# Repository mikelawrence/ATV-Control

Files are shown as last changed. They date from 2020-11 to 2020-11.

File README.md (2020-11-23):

# ATV Control PCB

This board was designed to act as a relay for two LED (V1 and V2) lights up to 7.5A each and a horn (H) up to 20A. Each LED Output has a control switch input and indicator LED output. When the Ignition input is on (12V) indicates the ATV is running so the Reverse input will turn LED V2 output on when at 12V and the High Beam input will turn LED V1 output on when at 12V. Turning Ignition off (0V) will turn off all LED outptus (V1 and V2). The control switches allows manual control the LED lights even when the ATV off. When you turn a LED on with a control switch the LED light will remain on for a configurable amount of time (1-20 minutes). This delay off will prevent the battery from being discharged.

The horn is controlled by a switch just like the LED outputs but it has three indicator LEDs (Red, Green, and Blue). When the horn control switch is pressed any currently on LED outputs (V1 or V2) will be turned off to reduce overall current throught the board. The horn will not work if Ignition is not on (12V).

## Status and Testing

* Rev 1.0 has been ordered and tested.
  * You can order parts from Mouser using this [shared BOM](https://www.mouser.com/ProjectManager/ProjectDetail.aspx?AccessID=3e10d07292).
  * You can order the PCB from [OSH Park](https://oshpark.com/shared_projects/YVj5Y8EP).

## Board Preview

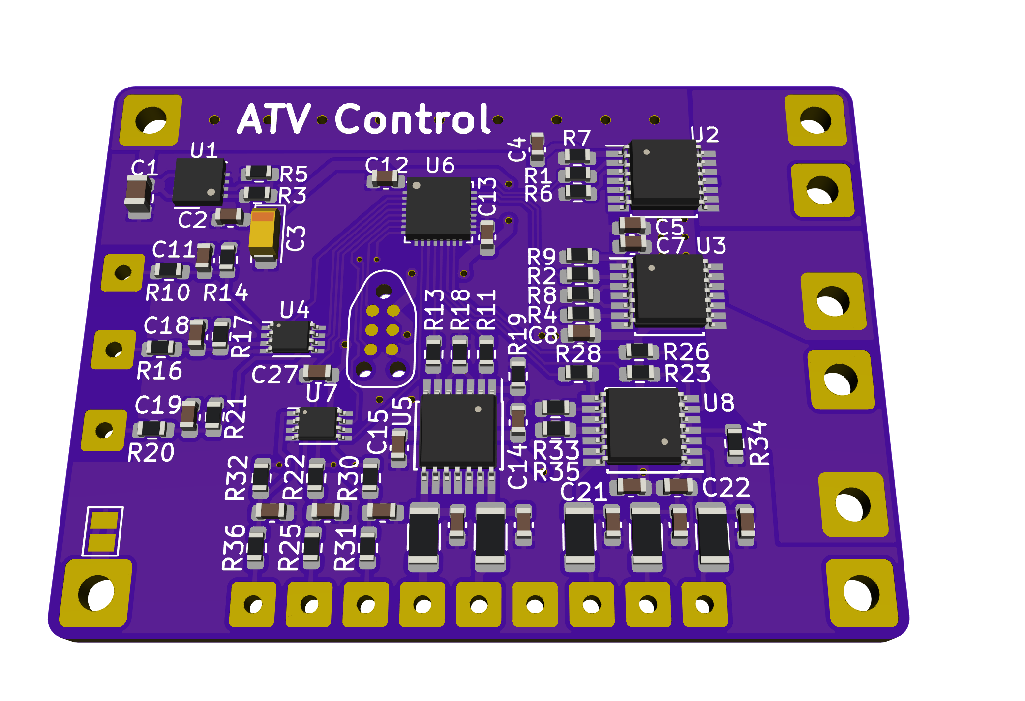
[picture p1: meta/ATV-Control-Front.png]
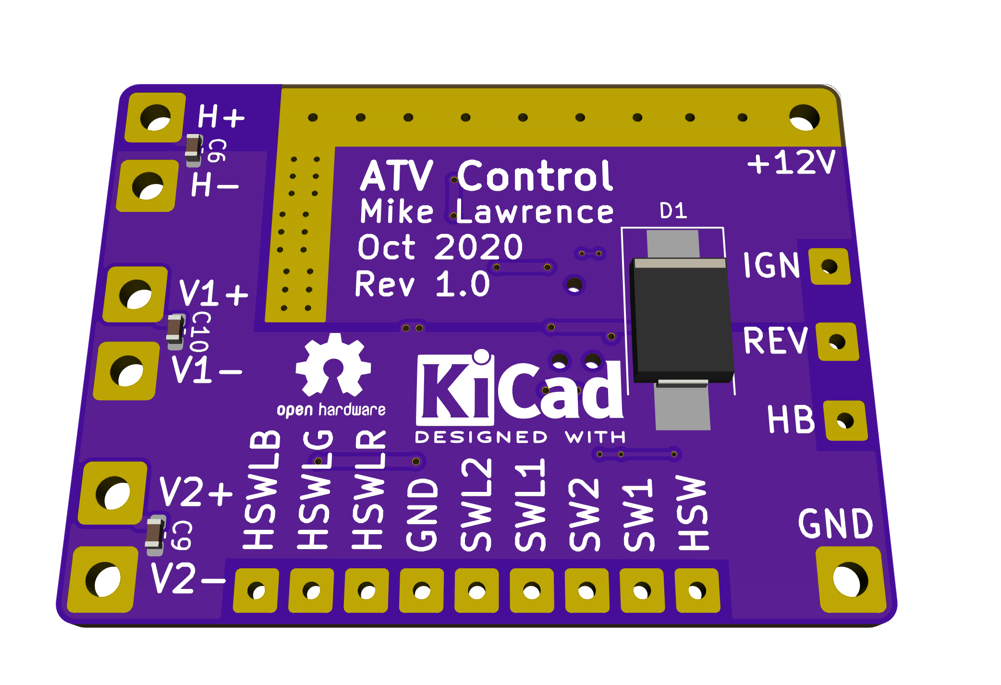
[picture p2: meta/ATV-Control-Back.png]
 

## Notes

* This board must have a 20A fuse or other safety device on the input.
* The Reverse Input is configured for my 2020 Yamaha Grizzly 700. The reverse switch is connected to ground when ATV is in reverse, otherwise it is pulled up to 12V by the Engine Control Unit. R17 is used to pulldown this input to prevent a floating input from causing problems. However this pulldown is a high enough impedance to not affect the pullup in the Engine Control Unit. You will need to adjust this input to match your specific ATV.
* The board's current usage is about than 0.25 mA when idle. This represents a small but never the less non-zero current draw on the ATV's battery even when the ignition is off. My ATV is used frequently so this is not an issue but if you plan on storing the ATV long term you should be using a trickle charger to keep the battery topped off. Or pull that 20 A fuse you added to the 12V input to this PCB.
* I used High-Side switch from Infineon for all the high current outputs. These chips are designed for automotive environments to drive resistive, capacitive, and inductive loads while providing over current, over temperature, over voltage, and reverse polarity protections. I also used these High-Side Switches for the indicator LEDs even though it is a bit overkill.
* The Horn circuit is a relatively high current at 20A. There is missing solder mask on the bottom of the PCB. It is expected that additional solder will be placed on this section to improve current handling. You should also plan on adding a 16 AWG wire between the GND input and the H- connections.
* This PCB design expects 2 oz copper for both sides.
* Assembling this PCB will require a reflow oven or hot air. [Whizoo](http://www.whizoo.com/) sells a nice kit to make your own reflow oven.
* This PCB design uses my custom libraries available here [Mike's KiCad Libraries](https://github.com/mikelawrence/KiCad-Libraries).
* PCB is designed in [KiCad](http://kicad-pcb.org) which is a great free EDA toolset.
* For Bill of Materials generation I use my version of [KiBoM](https://github.com/mikelawrence/KiBoM) forked from [SchrodingersGat](https://github.com/SchrodingersGat/KiBoM).

## Software

The microcontroller is a Atmel/Microchip XMega8E5. Software is written in C using the free [Microchip Studio for AVR](https://www.microchip.com/mplab/microchip-studio) free cross compiler and development environment. My normal AVR debugging tool is [Atmel-ICE](https://www.microchip.com/DevelopmentTools/ProductDetails/atatmel-ice). You can get it for as low as $62 in the form of a board from Digikey or Mouser. Instead of the standard programming header I use the Tag-Connect cable and it's space saving [footprint](https://www.tag-connect.com/product/tc2030-nl-fp-footprint). [This](https://www.tag-connect.com/product/tc2030-icespi-nl-no-leg-cable-for-use-with-atmel-ice) is Tag-Connect cable I use with the Atmel-ICE.

## Board Installation

I use Sugru moldable silicone to encapsulate this PCB to prevent water damage.

## End Result

The push button switches were installed in the center headlight cluster. Looking from the front the center pushbutton is the horn. The two push buttons on the right control the LED lights. The two buttons on the left are buttons for the Homelink controller ([60-HMLKV5BLK](https://www.amazon.com/gp/product/B00A79G9FY/ref=ppx_yo_dt_b_search_asin_title?ie=UTF8&psc=1)) so I can control my front gate and one garage door. This is not part of the ATV Control PCB.

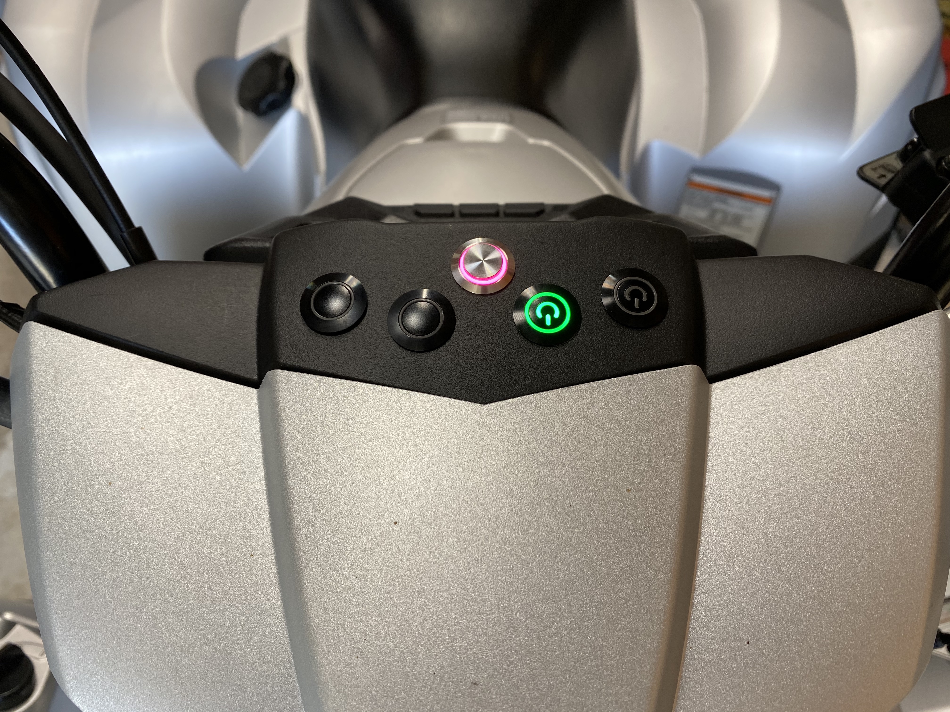
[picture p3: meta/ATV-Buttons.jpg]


For the front of the ATV I installed a Black Oak [10" Dual Row, 100W Flood LED Light Bar](https://www.blackoakled.com/collections/double-row-led/products/10-two-row-led-light-bar-combination-beam-pattern-white-osram) and two Black Oak [2" Single Row, 20W Scene LED Light Bars](https://www.blackoakled.com/products/new-2-inch-single-row-series-led-light-bar-with-scene-optics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). All three LED Light Bars draw just under 7 A which is just below the maximum current of 7.5 A for that output. I used Axia Alloy mounts for the LED Light Bars. They are expensive but look good and are strong at the same time. The front rack on the 2020 Grizzly is 7/8" in diameter.



I added a Black Oak [2" 40W Diffused LED Pod Light](https://www.blackoakled.com/products/new-2-inch-diffused-pod-light-powerful-turret-style-pod-40w-cree-xm-l2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) to the rear of the ATV mainly as a backup light. This LED Light draws 4.1 A which is just fine for the LED outputs. The accessory brush guard has a nice mounting point for this light right in the middle and well protected.



Here is a picture taken at night just after dusk. This is the front shot with all three light bars on. The fence line is 200 ft away and the shot is from behind the ATV. The slightly different color temperature on the left and right shows how the small light bars increase the visiblity on the sides. I'm happy with the results.

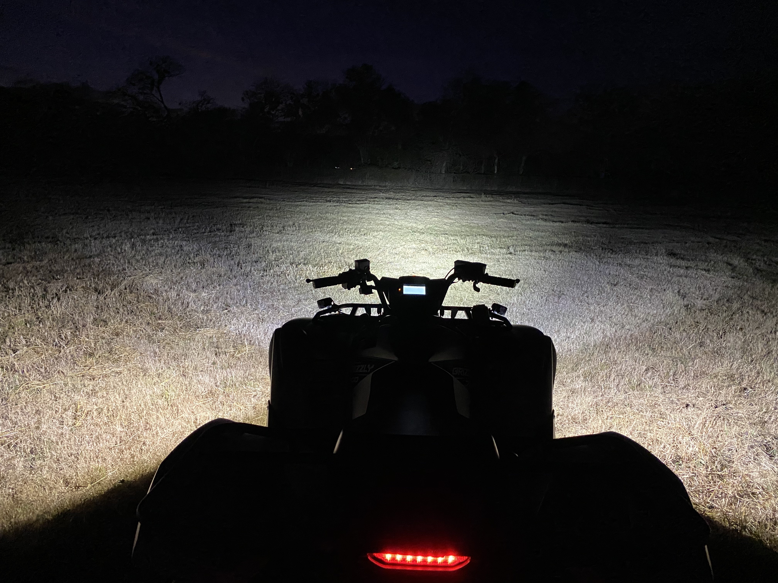
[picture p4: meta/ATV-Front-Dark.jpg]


This the rear shot again slightly after dusk with the rear pointed at the same fence line but about 25 ft away. The diffuse optics make the light more even, less sharp. It probably decreases the overall light output for a more pleasing distrubution. You loose distance for more even coverage.



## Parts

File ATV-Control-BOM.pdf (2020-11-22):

# ATV Control BOM Rev 1.0

Quantity | References | Value | Description | Manufacturer | Part Number | Vendor | Vendor Part Number
1 | C1 | 1uF | CAP, 0805, 1uF, 10%, X7S, 100V | Murata Electronics | GRJ21BC72A105KE11L | Mouser | 81-GRJ21BC72A105KE1L
4 | C2 C12 C13 C27 | 0.47uF | CAP, 0603, 0.47uF, 10%, X7R, 16V | Murata Electronics | GRM188R71C474KA88 | Mouser | 81-GRM188R71C474KA88
1 | C3 | 10uF | CAP, A Size, 10uF, 20%, Tantalum, 16V | Kemet | T491A106M016AT7280 | Mouser | 80-T491A106M016AT7280
4 | C4 C7 C14 C21 | 47nF | CAP, 0603, 47nF, 10%, X8R, 100V | Murata Electronics | GCJ188R92A473KA1D | Mouser | 81-GCJ188R92A473KA1D
4 | C5 C8 C15 C22 | 0.1uF | CAP, 0603, 0.1uF, 10%, X8R, 100V | Murata Electronics | GCJ188R72A104KA1D | Mouser | 81-GCJ188R72A104KA1D
14 | C6 C9 C10 C11 C16 C17 C18 C19 C20 C23 C24 C25 C26 C28 | 10nF | CAP, 0603, 10nF, 10%, X7R, 100V | Murata Electronics | GCM188R72A103KA7D | Mouser | 81-GCM188R72A103KA7D
1 | D1 | SM15T33CA | TVS, SMC, Bi-directional, 1500W | ST | SM15T33CA | Mouser | 511-SM15T33CA
8 | R1 R2 R4 R11 R13 R23 R26 R28 | 4.7k | RES, 0603, 4.7k, 1/10W, 5%, T100 | Yageo | RC0603JR-074K7L | Mouser | 603-RC0603JR-074K7L
1 | R3 | 2.15M | RES, 0603, 2.15M, 1/10W, 1%, T100 | Vishay | CRCW06032M15FKEA | Mouser | 71-CRCW06032M15FKEA
2 | R5 R17 | 1.27M | RES, 0603, 1.27M, 1/10W, 1%, T100 | Vishay | CRCW06031M27FKEA | Mouser | 71-CRCW06031M27FKEA
8 | R6 R8 R18 R25 R31 R33 R34 R36 | 10k | RES, 0603, 10k, 1/10W, 5%, T100 | Yageo | RC0603JR-0710KL | Mouser | 603-RC0603JR-0710KL
4 | R7 R9 R19 R35 | 47R | RES, 0603, 47R, 1/10W, 5%, T100 | Yageo | RC0603FR-0747RL | Mouser | 603-RC0603FR-0747RL
8 | R10 R14 R16 R20 R21 R22 R30 R32 | 100k | RES, 0603, 100k, 1/10W, 5%, T100 | Yageo | RC0603JR-07100KL | Mouser | 603-RC0603JR-07100KL
5 | R12 R15 R24 R27 R29 | 560R | RES, 1206, 560R, 1/2W, 5%, T200 | Panasonic | ERJ-8GEYJ561V | Mouser | 667-ERJ-8GEYJ561V
1 | U1 | LT3014IDD | IC, DFN-8, Linear Regulator, LDO, 80V, 20mA | Linear Tech | LT3014BHVIDD#PBF | Mouser | 584-LT3014BHVIDD#PBF
1 | U2 | BTS7002-1EPP | IC, TSDSO-14, High-Side Switch, Single, 21A | Infineon | BTS70021EPPXUMA1 | Mouser | 726-BTS70021EPPXUMA1
1 | U3 | BTS7008-2EPA | IC, TSDSO-14, High-Side Switch, Dual, 7.5A | Infineon | BTS70082EPAXUMA1 | Mouser | 726-BTS70082EPAXUMA1
2 | U4 U7 | 74LVC3G17 | IC, VSSOP-8, Triple Schmitt-Trigger Buffer | TI | SN74LVC3G17DCUR | Mouser | 595-SN74LVC3G17DCUR
1 | U5 | BTS7200-2EPA | IC, TSDSO-14, High-Side Switch, Dual, 1.2A | Infineon | BTS72002EPAXUMA1 | Mouser | 726-BTS72002EPAXUMA1
1 | U6 | ATXMEGA8E5-M4U | IC, QFN-32, 8/16-bit AVR XMEGA Microcontroller, 8kB | Atmel | ATXMEGA8E5-M4U | Mouser | 556-ATXMEGA8E5-M4U
1 | U8 | BTS7200-4EPA | IC, TSDSO-14, High-Side Switch, Quad, 1A | Infineon | BTS72004EPAXUMA1 | Mouser | 726-BTS72004EPAXUMA1

1

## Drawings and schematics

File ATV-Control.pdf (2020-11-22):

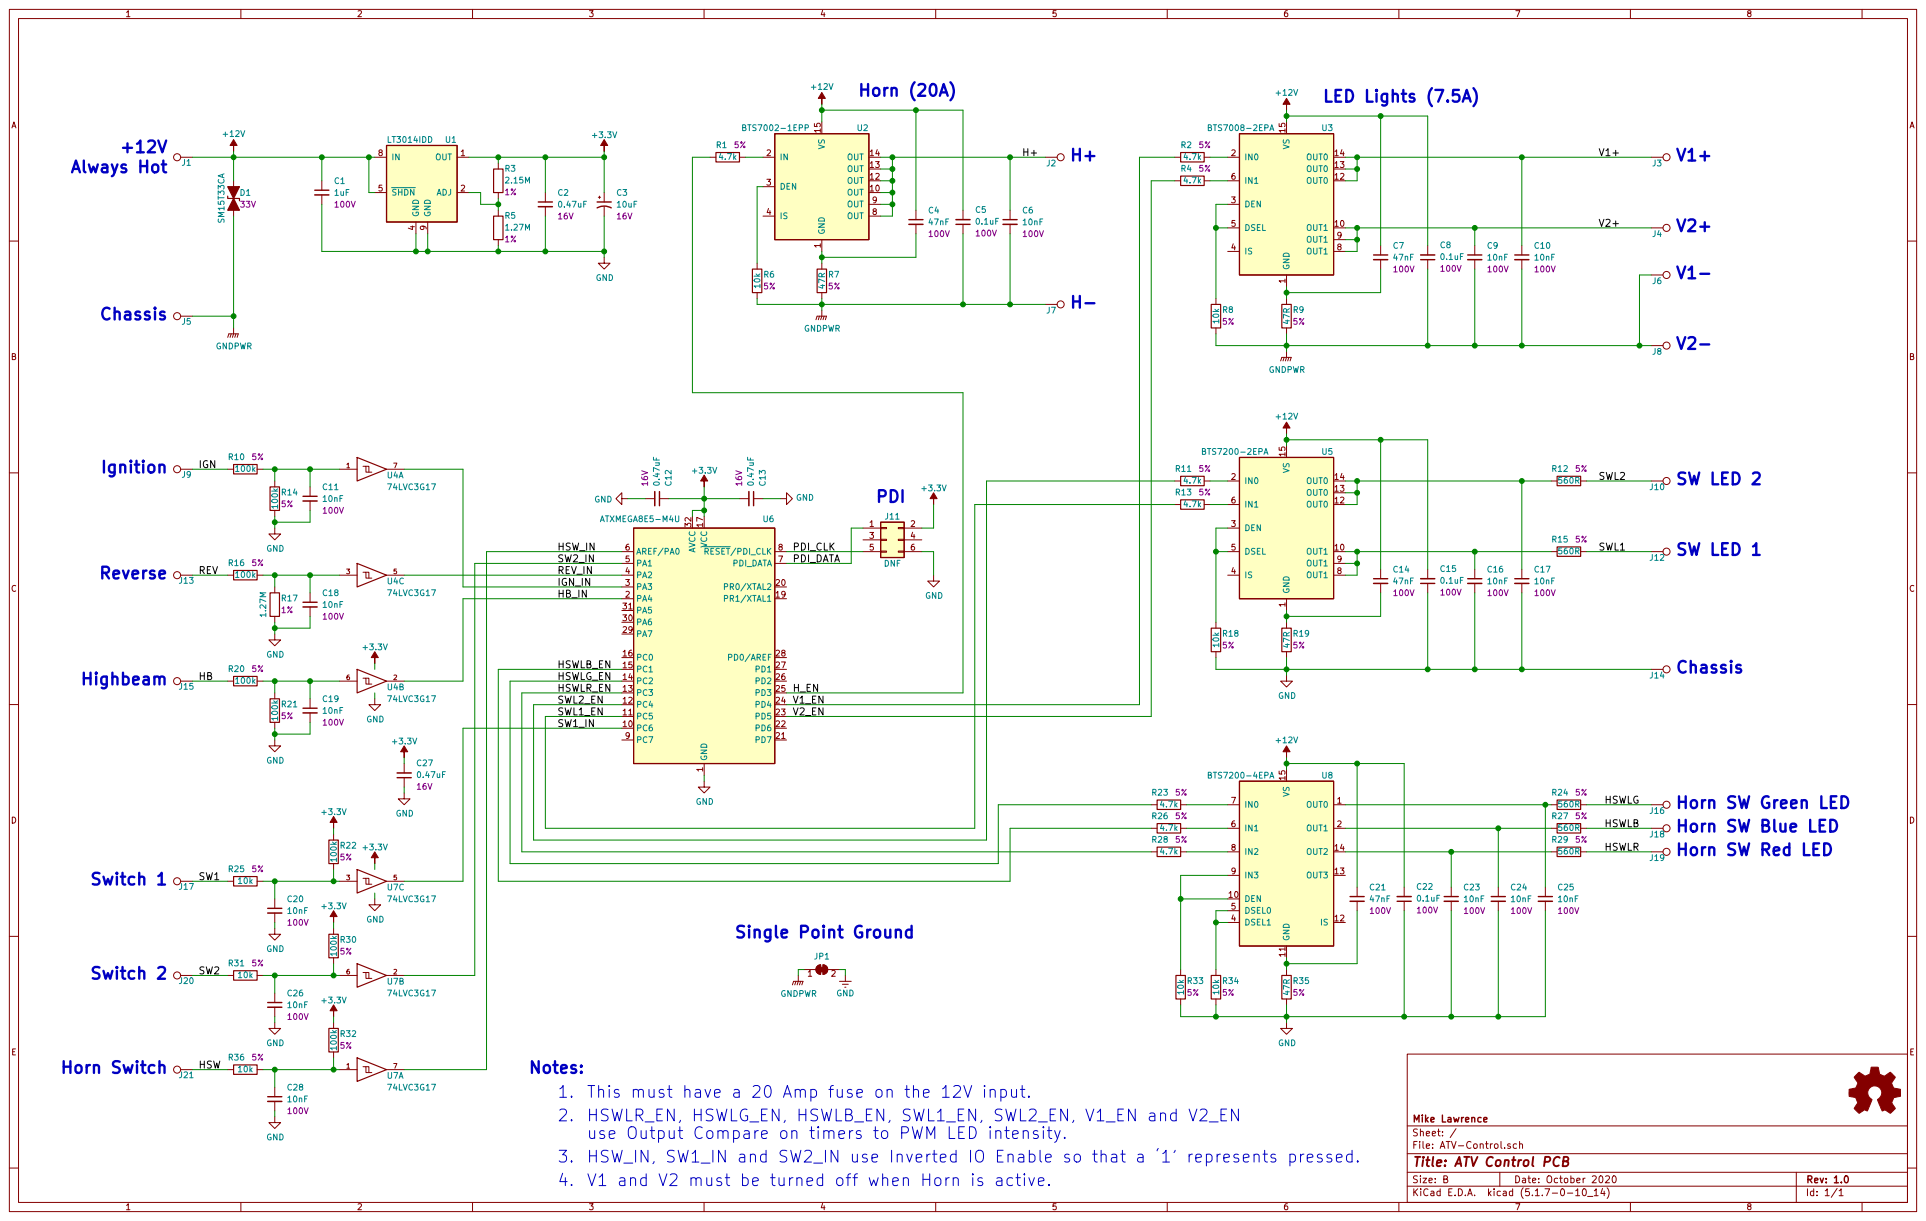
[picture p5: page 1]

1 OUT 10 OUT 12 OUT 13 OUT 14 VS 15

1 PC6 10 PC5 11 PC4 12 PC3 13 PC2 14 PC1 15 PC0 16 VCC 17 PR1/XTAL1 19 PA4 2 PR0/XTAL2 20 PD7 21 PD6 22 PD5 23 PD4 24 PD3 25 PD2 26 PD1 27 PD0/AREF 28 PA7 29 PA3 3 PA6 30 PA5 31 AVCC 32 PA2 4 PA1 5 AREF/PA0 6 PDI_DATA 7 RESET/PDI_CLK 8 PC7 9 ATXMEGA8E5-M4U U6 +3.3V 16V 0.47uF C12 16V 0.47uF C13

REV_IN
IGN_IN
HB_IN

HSWLG_EN
HSWLR_EN
SWL2_EN | | V1_EN
SWL1_EN | | V2_EN
SW1_IN

Horn SW Green LED
Horn SW Blue LED
Horn SW Red LED

Notes:
1. This must have a 20 Amp fuse on the 12V input.
2. HSWLR_EN, HSWLG_EN, HSWLB_EN, SWL1_EN, SWL2_EN, V1_EN and V2_EN
use Output Compare on timers to PWM LED intensity.
3. HSW_IN, SW1_IN and SW2_IN use Inverted IO Enable so that a 1 represents pressed.
4. V1 and V2 must be turned off when Horn is active.

File: ATV-Control.sch Sheet: / Mike Lawrence

Id: 1/1 Title: ATV Control PCB

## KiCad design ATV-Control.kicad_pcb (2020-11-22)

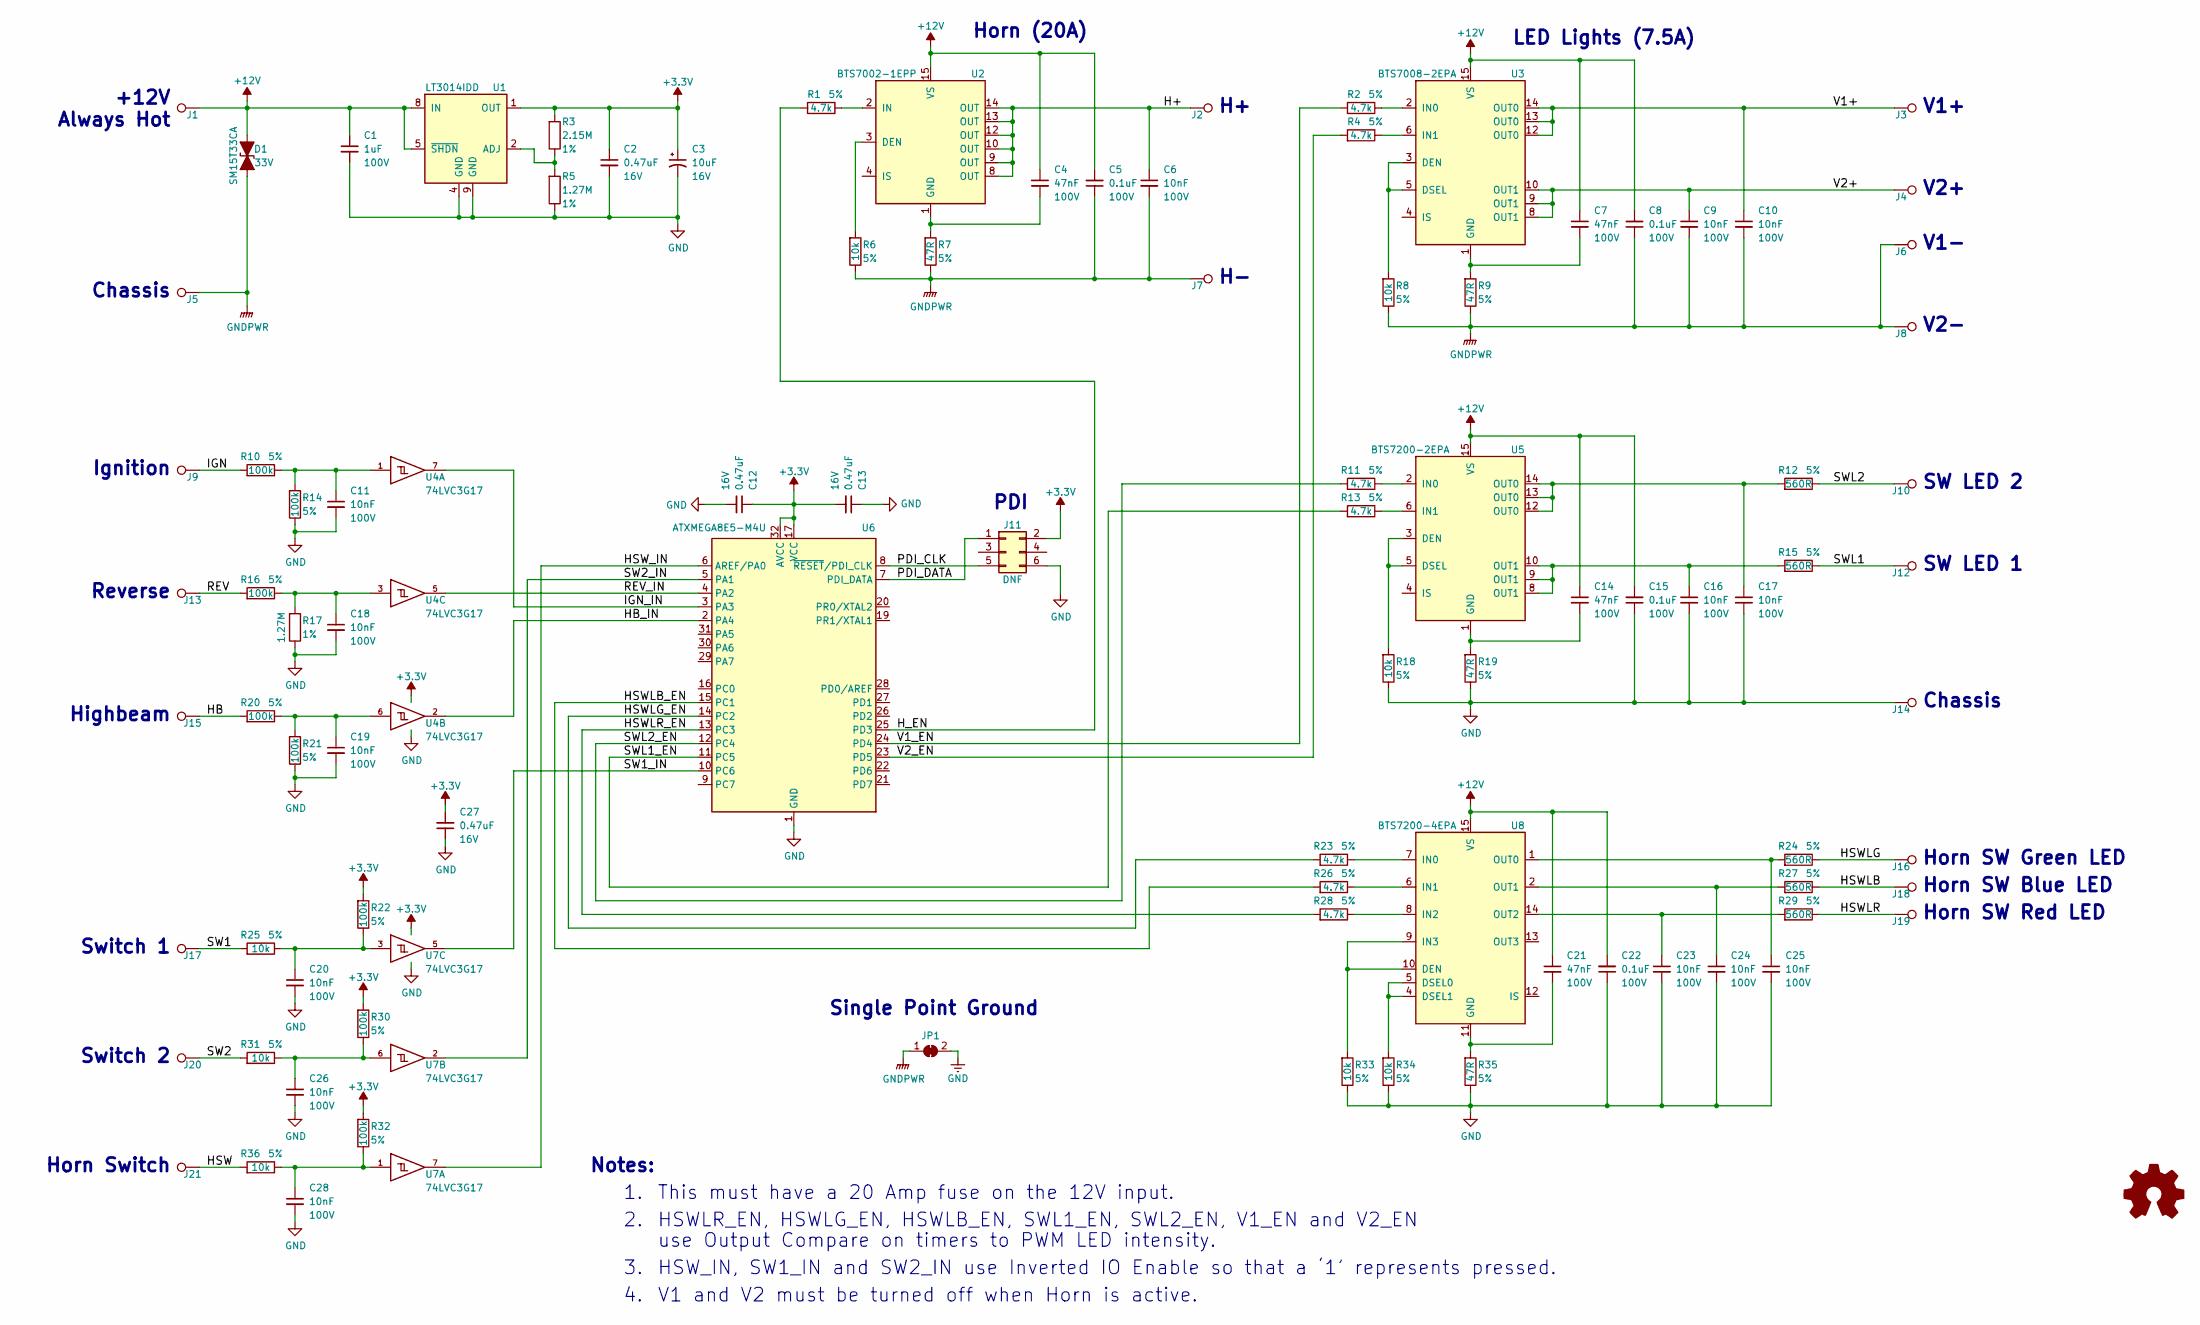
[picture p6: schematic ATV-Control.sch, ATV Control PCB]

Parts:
C1: 1uF; C_0805_2012Metric; Voltage 100V; Part Number GRJ21BC72A105KE11L
C2, C12, C13, C27: 0.47uF; C_0603_1608Metric; Voltage 16V; Part Number GRM188R71C474KA88
C3: 10uF; CP_EIA-3216-18_Kemet-A; Tolerance 20%; Voltage 16V; Part Number T491A106M016AT7280
C4, C7, C14, C21: 47nF; C_0603_1608Metric; Voltage 100V; Part Number GCJ188R92A473KA1D
C5, C8, C15, C22: 0.1uF; C_0603_1608Metric; Voltage 100V; Part Number GCJ188R72A104KA1D
C6, C9, C10, C11, C16, C17, C18, C19, C20, C23, C24, C25, C26, C28: 10nF; C_0603_1608Metric; Voltage 100V; Part Number GCM188R72A103KA7D
D1: SM15T33CA; D_SMC_Handsoldering; Voltage 33V; Part Number SM15T33CA
J1, J2, J3, J4, J5, J6, J7, J8: TEST_1P; SolderWire-1x01_D2mm_OD3.81mm
J9, J10, J12, J13, J14, J15, J16, J17, J18, J19, J20, J21: TEST_1P; SolderWire-1x01_D1mm_OD2.54mm
J11: DNF; TC2030-IDC-NP; Part Number TC2030-ICESPI-NL
JP1: Jumper; SolderJumper-2_P1.3mm_Bridged2Bar_Pad1.0x1.5mm
R1, R2, R4, R11, R13, R23, R26, R28: 4.7k; R_0603_1608Metric; Tolerance 5%; Part Number RC0603JR-074K7L
R3: 2.15M; R_0603_1608Metric; Tolerance 1%; Part Number CRCW06032M15FKEA
R5, R17: 1.27M; R_0603_1608Metric; Tolerance 1%; Part Number CRCW06031M27FKEA
R6, R8, R18, R25, R31, R33, R34, R36: 10k; R_0603_1608Metric; Tolerance 5%; Part Number RC0603JR-0710KL
R7, R9, R19, R35: 47R; R_0603_1608Metric; Tolerance 5%; Part Number RC0603FR-0747RL
R10, R14, R16, R20, R21, R22, R30, R32: 100k; R_0603_1608Metric; Tolerance 5%; Part Number RC0603JR-07100KL
R12, R15, R24, R27, R29: 560R; R_1206_3216Metric; Tolerance 5%; Part Number ERJ-8GEYJ561V
U1: LT3014IDD; DFN-8-1EP_3x3mm_P0.5mm_EP1.66x2.38mm; Part Number LT3014BHVIDD#PBF
U2: BTS7002-1EPP; Infineon_PG-TSDSO-14-22; Part Number BTS70021EPPXUMA1
U3: BTS7008-2EPA; Infineon_PG-TSDSO-14-22; Part Number BTS70082EPAXUMA1
U4, U7: 74LVC3G17; VSSOP-8_2.3x2mm_P0.5mm; Part Number SN74LVC3G17DCUR
U5: BTS7200-2EPA; Infineon_PG-TSDSO-14-22; Part Number BTS72002EPAXUMA1
U6: ATXMEGA8E5-M4U; QFN-32-1EP_4x4mm_P0.4mm_EP2.65x2.65mm; Part Number ATXMEGA8E5-M4U
U8: BTS7200-4EPA; Infineon_PG-TSDSO-14-22; Part Number BTS72004EPAXUMA1

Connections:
+3.3V: C2.1, C3.1, C12.1, C13.2, C27.2, J11.2, R3.2, R22.2, R30.2, R32.2, U1.1 (OUT), U4.8 (VCC), U6.17 (VCC), U6.32 (AVCC), U7.8 (VCC)
+12V: C1.1, C4.1, C5.2, C7.1, C8.2, C14.1, C15.2, C21.1, C22.2, D1.1 (A1), J1.1, U1.5 (~SHDN), U1.8 (IN), U2.15 (VS), U3.15 (VS), U5.15 (VS), U8.15 (VS)
/H+: C6.1, J2.1, U2.8 (OUT), U2.9 (OUT), U2.10 (OUT), U2.12 (OUT), U2.13 (OUT), U2.14 (OUT)
/HB: J15.1, R20.2
/HB_IN: U4.2, U6.2 (PA4)
/HSW: J21.1, R36.2
/HSWLB: J18.1, R27.1
/HSWLB_EN: R26.2, U6.15 (PC1)
/HSWLG: J16.1, R24.1
/HSWLG_EN: R23.2, U6.14 (PC2)
/HSWLR: J19.1, R29.1
/HSWLR_EN: R28.2, U6.13 (PC3)
/HSW_IN: U6.6 (AREF/PA0), U7.7
/H_EN: R1.2, U6.25 (PD3)
/IGN: J9.1, R10.2
/IGN_IN: U4.7, U6.3 (PA3)
/PDI_CLK: J11.5, U6.8 (~RESET~/PDI_CLK)
/PDI_DATA: J11.1, U6.7 (PDI_DATA)
/REV: J13.1, R16.2
/REV_IN: U4.5, U6.4 (PA2)
/SW1: J17.1, R25.2
/SW1_IN: U6.10 (PC6), U7.5
/SW2: J20.1, R31.2
/SW2_IN: U6.5 (PA1), U7.2
/SWL1: J12.1, R15.1
/SWL1_EN: R13.2, U6.11 (PC5)
/SWL2: J10.1, R12.1
/SWL2_EN: R11.2, U6.12 (PC4)
/V1+: C10.1, J3.1, U3.12 (OUT0), U3.13 (OUT0), U3.14 (OUT0)
/V1_EN: R2.2, U6.24 (PD4)
/V2+: C9.1, J4.1, U3.8 (OUT1), U3.9 (OUT1), U3.10 (OUT1)
/V2_EN: R4.2, U6.23 (PD5)
GND: C1.2, C2.2, C3.2, C11.2, C12.2, C13.1, C15.1, C16.2, C17.2, C18.2, C19.2, C20.2, C22.1, C23.2, C24.2, C25.2, C26.2, C27.1, C28.2, J11.6, J14.1, JP1.2 (B), R5.1, R14.1, R17.1, R18.1, R19.1, R21.1, R33.1, R34.1, R35.1, U1.4 (GND), U1.9 (GND), U4.4 (GND), U6.1 (GND), U6.18 (GND), U6.33 (GND), U7.4 (GND)
GNDPWR: C5.1, C6.2, C8.1, C9.2, C10.2, D1.2 (A2), J5.1, J6.1, J7.1, J8.1, JP1.1 (A), R6.1, R7.1, R8.1, R9.1
unnamed: C4.2, R7.2, U2.1 (GND)
unnamed: C7.2, R9.2, U3.1 (GND)
unnamed: C11.1, R10.1, R14.2, U4.1
unnamed: C14.2, R19.2, U5.1 (GND)
unnamed: C16.1, R15.2, U5.8 (OUT1), U5.9 (OUT1), U5.10 (OUT1)
unnamed: C17.1, R12.2, U5.12 (OUT0), U5.13 (OUT0), U5.14 (OUT0)
unnamed: C18.1, R16.1, R17.2, U4.3
unnamed: C19.1, R20.1, R21.2, U4.6
unnamed: C20.1, R22.1, R25.1, U7.3
unnamed: C21.2, R35.2, U8.11 (GND)
unnamed: C23.1, R29.2, U8.14 (OUT2)
unnamed: C24.1, R27.2, U8.2 (OUT1)
unnamed: C25.1, R24.2, U8.1 (OUT0)
unnamed: C26.1, R30.1, R31.1, U7.6
unnamed: C28.1, R32.1, R36.1, U7.1
unnamed: R1.1, U2.2 (IN)
unnamed: R2.1, U3.2 (IN0)
unnamed: R3.1, R5.2, U1.2 (ADJ)
unnamed: R4.1, U3.6 (IN1)
unnamed: R6.2, U2.3 (DEN)
unnamed: R8.2, U3.3 (DEN), U3.5 (DSEL)
unnamed: R11.1, U5.2 (IN0)
unnamed: R13.1, U5.6 (IN1)
unnamed: R18.2, U5.3 (DEN), U5.5 (DSEL)
unnamed: R23.1, U8.7 (IN0)
unnamed: R26.1, U8.6 (IN1)
unnamed: R28.1, U8.8 (IN2)
unnamed: R33.2, U8.9 (IN3), U8.10 (DEN)
unnamed: R34.2, U8.4 (DSEL1), U8.5 (DSEL0)

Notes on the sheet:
PDI
Highbeam
Ignition
Reverse
V2-
V1-
V2+
V1+
+12V Always Hot
SW LED 1
SW LED 2
Chassis
Horn SW Red LED
Horn SW Green LED
Horn SW Blue LED
Horn Switch
Switch 1
Switch 2
Single Point Ground
Horn (20A)
LED Lights (7.5A)
Notes:
HSWLR_EN, HSWLG_EN, HSWLB_EN, SWL1_EN, SWL2_EN, V1_EN and V2_EN
use Output Compare on timers to PWM LED intensity.
HSW_IN, SW1_IN and SW2_IN use Inverted IO Enable so that a ‘1’ represents pressed.
V1 and V2 must be turned off when Horn is active.
This must have a 20 Amp fuse on the 12V input.

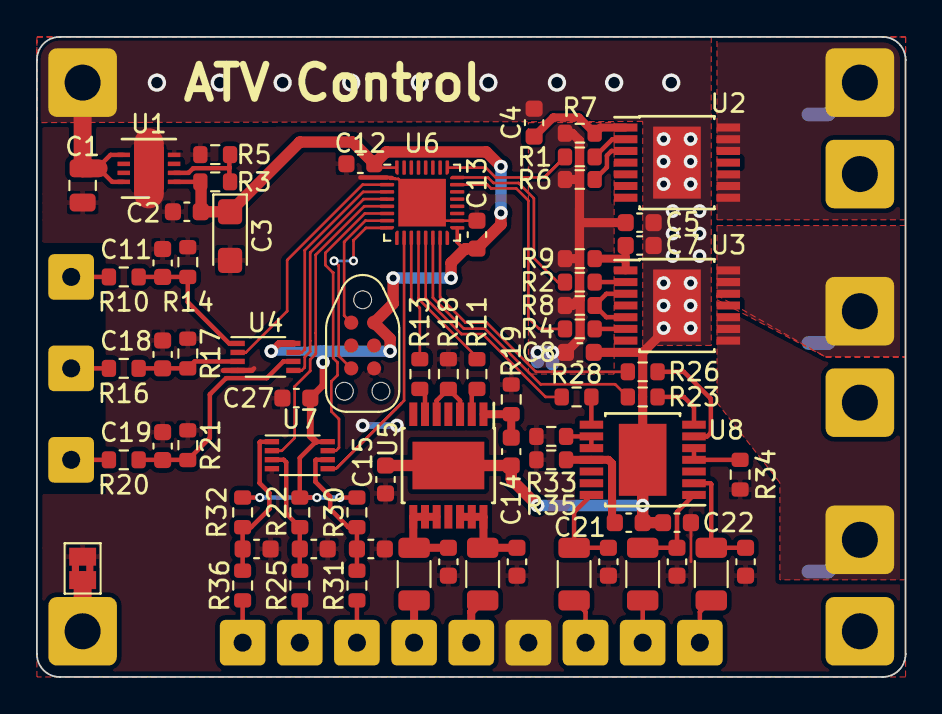
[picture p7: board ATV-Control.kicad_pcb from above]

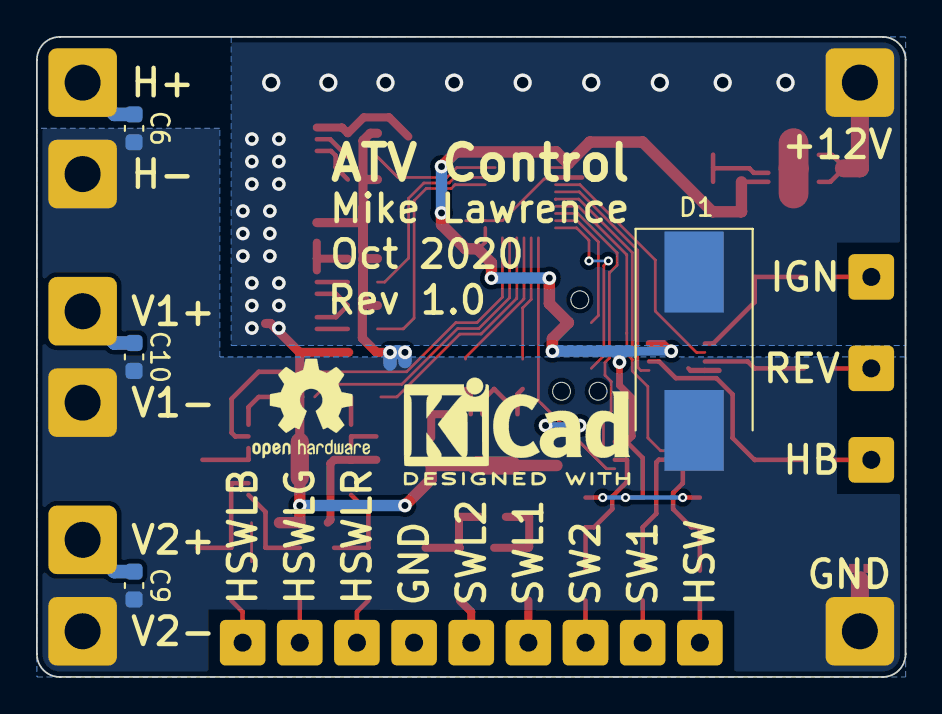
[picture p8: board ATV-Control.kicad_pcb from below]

Board: 2 copper layers, 48.3 x 35.6 mm, 95 parts (4 on the bottom side), 63 nets.

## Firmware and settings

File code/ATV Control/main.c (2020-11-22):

/*
 * ATV Control
 * Rev 1.0
 *
 * The main application of this module is to replace three mechanical relays, two for for LEDs and one
 * for a horn on my ATV.
 *
 * The main output is the Horn which supports up to 20A. A pushbutton switch is used to honk the Horn but 
 * only when the ATV is on (Ignition input 12V). The other LED Outputs (V1 and V2) are turned off just 
 * before the Horn is activated. This keeps the total board maximum current to 20A. The other LED outputs 
 * will return to their previous state once the Horn pushbutton is released. The LED indicator on the Horn.
 * switch is RGB. When the ATV is turned on (Ignition input 12V) the Horn indicator LED will cycle through
 * the color spectrum. When the Horn is engaged the indicator LED will flash red.
 *
 * The other two 12V outputs (V1 and V2) support 7.5A each and are controlled by pushbutton switches 
 * (Switch 1 and Switch 2). These pushbutton switches will turn off/on the outputs at any time. If the ATV
 * is off (Ignition input 0V) and an Output is turned on it will remain on for a user configurable amount 
 * of time before automatically turning off. When the ATV is turned off (Ignition input 0V) all Outputs are 
 * automatically turned off. These outputs are connected to TCD5 which would allow dimming of LEDs connected
 * to them but this is currently not part of the code below.
 *
 * In addition to pushbutton control the outputs are automatically enabled by other control inputs. 
 * V1 Output is turned on when the High beam input is turned on (HB input 12V).
 * V2 Output is turned on when the ATV is put into reverse (REV input 12V).
 * When V1 and V2 Outputs are turned on via HB or REV inputs the LED indicator intensity breathes.
 *
 * Delay time to turn Outputs off when Ignition is off is configurable.
 *
 * To enter program mode do the following:
 *  1. Press and Hold both Switch 1 and Switch 2 for 10 seconds.
 *  2. Release both Switch 1 and Switch 2.
 *  3. Switch LEDs should be flashing.
 *  4. Delay time is now defaulted to 0 which means outputs cannot be turned on when Ignition is off.
 *  5. Each time you press and release either switch you will add one minute to the delay.
 *     While either switch is pressed the LED will stop flashing and remain lit.
 *  6. Once you have configured the desired delay wait for 10 seconds (LEDs will be flashing).
 *  7. When the 10 seconds has elapsed the LEDS will slow flash the newly configured number of minutes
 *     as confirmation.
 *
 * Created: 10/25/2020
 * Author : Mike Lawrence
 */

/*
 * System Clock is kept at the power on default of Internal 2MHz. Internal 32.768 kHz clock is also enabled.
 *
 * RTC clock is set to Internal 32.768kHz. RTC is configured for a 1ms overflow. The overflow rate is 0.708%
 * longer than 1ms but precision timing is not the goal here. The RTC Overflow Interrupt is used to keep track 
 * of millisecond counters (tick_ms, delay_ms, prog_ms and led_ms).
 * 
 * The HSW, SW1, SW2, IGN, HB and REV inputs are configured so that any input change will automatically wake
 * the processor from an idle state. The idle state is entered only when Ignition is off (IGN at 0V) and no 
 * LED outputs (V1 and V2) are currently on. HSW, HB and REV inputs are ignored when Ignition is off.
 *
 * All indicator LEDs (HSWLR_EN, HSWLG_EN, HSWLG_EN, SW1L_EN and SW2L_EN) outputs are controlled by 
 * Output Compares which allows PWM of the LED (brightness adjustment).
 * 
 * The main LED outputs V1 and V2 are connected to pins that can be used as Output Compares. So it is possible
 * to use PWM to modulate Output LED light intensity. Currently this code does not support this.
 * Both V1 and V2 can a fixed maximum and a soft start and stop.
 *
 */

#include <avr/io.h>
#include <avr/eeprom.h>
#include <avr/fuse.h>
#include <avr/interrupt.h>
#include <avr/pgmspace.h>
#include <avr/sleep.h>
#include <avr/wdt.h>
#include "math.h"

/*
 * Fuse definitions
 */
FUSES =
{
	// FuseByte 1 = Watchdog timeouts set to 1,000 clocks or 1 s
	.FUSEBYTE1 = 0xFF & (WDWPER_1KCLK_gc | ~NVM_FUSES_WDWPER_gm) & (WDPER_1KCLK_gc | ~NVM_FUSES_WDPER_gm),		
	// FuseByte 2 = Application reset vector enabled, BOD is sampled in Power Down Mode
	.FUSEBYTE2 = 0xFF & (BOOTRST_APPLICATION_gc | ~NVM_FUSES_BOOTRST_bm) & (BODPD_SAMPLED_gc | ~NVM_FUSES_BODPD_gm),		
	// FuseByte 4 = Ext Reset is not disabled, Start Up Time is 0 ms, Watchdog timer is not locked 
	.FUSEBYTE4 = 0xFF & /* FUSE_RSTDISBL & */ (STARTUPTIME_0MS_gc | ~NVM_FUSES_STARTUPTIME_gm) /* & FUSE_WDLOCK */,							
	// FuseByte 5 = BOD continuous in Active Modes, EEPROM saved during chip erase, BOD Level is 2.0V
	.FUSEBYTE5 = 0xFF & (BODACT_CONTINUOUS_gc | ~NVM_FUSES_BODACT_gm) & FUSE_EESAVE & (BODLEVEL_2V0_gc | ~NVM_FUSES_BODLEVEL_gm), 
	// FuseByte 5 = Timer fault and detection defaults
	.FUSEBYTE6 = 0xFF
};

/*
 * Application specific definitions
 */
#define FALSE							0
#define TRUE							1
#define OFF								FALSE
#define ON								TRUE
// Default number of minutes LEDs stay on when turned one with Ignition Off
#define DEFAULT_DELAY_TIME_MINUTES		5
// Number of seconds to activate programming sequence
#define PROG_ACTIVATE_SECONDS			10
// Number of milliseconds for LED to be ON or OFF when flashing
#define LED_FLASH_TIME					500
// Timer Period that will produce normal PWM frequency for LED outputs
// FREQ = CPU_FREQ / 2 * 64 * PER (PER = 255 = 61.27 Hz)
#define OUT_PWM_PERIOD					255
// Timer Period that will produce normal PWM frequency 
// FREQ = CPU_FREQ / 2 * 64 * PER (PER = 255 = 61.27 Hz)
#define LED_PWM_PERIOD					255
// Timer Period that will produce a visible flash for Switch LED indicators
// FREQ = CPU_FREQ / 2 * 64 * PER (PER = 2047 = 7.65 Hz)
#define LED_FLASH_PERIOD				1500
// input debounce time in milliseconds (cannot be larger than 255)
#define DEBOUNCE_TIME					5
// Watchdog timeout setting
#define WATCHDOG_TO						WDTO_2S
// Output defines
#define HEN_port						PORTD
#define HEN_bp							PIN3_bp
#define V1EN_port						PORTD
#define V1EN_bp							PIN4_bp
#define V2EN_port						PORTD
#define V2EN_bp							PIN5_bp
#define HSWLREN_port					PORTC
#define HSWLREN_bp						PIN3_bp
#define HSWLGEN_port					PORTC
#define HSWLGEN_bp						PIN2_bp
#define HSWLBEN_port					PORTC
#define HSWLBEN_bp						PIN1_bp
#define SWL1EN_port						PORTC
#define SWL1EN_bp						PIN5_bp
#define SWL2EN_port						PORTC
#define SWL2EN_bp						PIN4_bp
// Input defines
#define IGN_port						PORTA
#define IGN_bp							PIN3_bp
#define REV_port						PORTA
#define REV_bp							PIN2_bp
#define HB_port							PORTA
#define HB_bp							PIN4_bp
#define HSW_port						PORTA
#define HSW_bp							PIN0_bp
#define SW2_port						PORTA
#define SW2_bp							PIN1_bp
#define SW1_port						PORTC
#define SW1_bp							PIN6_bp

/*
 * Constants
 */

const uint8_t PROGMEM quarter_sine[64] = {128, 131, 134, 137, 140, 143, 146, 149, 
										  152, 155, 158, 162, 165, 167, 170, 173,
										  176, 179, 182, 185, 188, 190, 193, 196,
										  198, 201, 203, 206, 208, 211, 213, 215,
										  218, 220, 222, 224, 226, 228, 230, 232, 
										  234, 235, 237, 238, 240, 241, 243, 244,
										  245, 246, 248, 249, 250, 250, 251, 252,
										  253, 253, 254, 254, 254, 255, 255, 255};
/*
 * Enumerations
 */
enum POWER_SM  { SM_POWER_RESET = 0, SM_POWER_DOWN, SM_POWER_ON_IGN, SM_POWER_ON_SW };
enum PROG_SM   { SM_PROG_RESET = 0, SM_PROG_ACTIVATE, SM_PROG_WAIT, SM_PROG_ON_WAIT, SM_PROG_OFF_WAIT, SM_PROG_DISPLAY_DWELL, SM_PROG_DISPLAY};
enum LED_STATE { LED_OFF = 0, LED_ON, LED_BREATHE, LED_FLASH };
enum SW_TOGGLE { TOGGLE_OFF = 0, TOGGLE_ON, TOGGLE_ON_USER };
enum SW_LED    { SW1_LED = 1, SW2_LED = 2, SW12_LED = 3 };

/* 
 * EEPROM variables
 */
uint32_t EEMEM eeprom_delay_time_ms = DEFAULT_DELAY_TIME_MINUTES * 60ul * 1000ul;

/*
 * Global variables (Note best code optimization (code size) requires all defaults to be 0)
 */
volatile uint8_t  tick_ms = 0;							// Free-running milliseconds tick counter (255 milliseconds max)
volatile uint32_t delay_ms = 0;							// Delay milliseconds counter
volatile uint32_t prog_ms = 0;							// Program milliseconds counter
volatile uint16_t led_ms = 0;							// LED milliseconds counter

volatile uint8_t  ign_db = FALSE;						// Ignition currently debouncing
volatile uint8_t  ign_dbtime = 0;						// Ignition debounce start time
volatile uint8_t  ign_cur = OFF;						// Current Ignition state
volatile uint8_t  ign_last = ON;						// Last Ignition state

volatile uint8_t  rev_db = FALSE;						// Reverse currently debouncing
volatile uint8_t  rev_dbtime = 0;						// Reverse debounce start time
volatile uint8_t  rev_cur = OFF;						// Current Reverse state
volatile uint8_t  rev_last = ON;						// Last Reverse state

volatile uint8_t  hb_db = FALSE;						// High beam currently debouncing
volatile uint8_t  hb_dbtime = 0;						// High beam debounce start time
volatile uint8_t  hb_cur = OFF;							// Current High beam state
volatile uint8_t  hb_last = ON;							// Last High beam state

volatile uint8_t  hsw_db = FALSE;						// Horn Switch currently debouncing
volatile uint8_t  hsw_dbtime = 0;						// Horn Switch debounce start time
volatile uint8_t  hsw_cur = OFF;						// Current Horn Switch state
volatile uint8_t  hsw_last = ON;						// Last Horn Switch state

volatile uint8_t  sw1_db = FALSE;						// Switch 1 currently debouncing
volatile uint8_t  sw1_dbtime = 0;						// Switch 1 debounce start time
volatile uint8_t  sw1_cur = OFF;						// Current Switch 1 state
volatile uint8_t  sw1_toggle = TOGGLE_OFF;				// Switch 1 toggle state
volatile uint8_t  sw1_led_intensity = 0;				// Current Switch 1 LED intensity (0-255)
volatile uint8_t  sw1_led_state = LED_OFF;				// Current Switch 1 LED state

volatile uint8_t  sw2_db = FALSE;						// Switch 2 currently debouncing
volatile uint8_t  sw2_dbtime = 0;						// Switch 2 debounce start time
volatile uint8_t  sw2_cur = OFF;						// Current Switch 2 state
volatile uint8_t  sw2_toggle = TOGGLE_OFF;				// Switch 2 toggle state
volatile uint8_t  sw2_led_intensity = 0;				// Current Switch 2 LED intensity (0-255)
volatile uint8_t  sw2_led_state = LED_OFF;				// Current Switch 2 LED state

/*
 * Return sine wave values offset at 128.
 *  Angle is 0-255 and represents a full period. 
 *  Output is 0-255. Non-negative.
 */
uint8_t get_sine(uint8_t angle)
{
	volatile uint8_t quad = (angle & 0xC0) >> 6;					// what quadrant of sine wave is this angle
	volatile uint8_t newang = angle;
	volatile uint8_t ang = newang & 0x3F;							// force angle into quad angle range 0-63
	
 	if (quad & 0x01)
 	{
 		ang = 63 - ang;									// angle should be reversed (Quadrant 2 and 4)
 	}
	uint8_t val = pgm_read_byte(&quarter_sine[ang]);	// get the value from the table
 	if (quad & 0x02)
 	{
 		val = 255 - val;								// invert value (Quadrant 3 and 4)
 	}
	return val;
}

/*
 * Return sine wave peak values no offset. 
 *  Any negative value returns a 0.
 *  Angle is 0-255 and represents a full period. 
 *  Output is 0-255. Non-negative.
 */
uint8_t get_sine_peak(uint8_t angle)
{
	volatile uint8_t quad = (angle & 0xC0) >> 6;					// what quadrant of sine wave is this angle
	volatile uint8_t newang = angle;
	volatile uint8_t ang = newang & 0x3F;							// force angle into quad angle range 0-63
	
 	if (quad & 0x01)
 	{
 		ang = 63 - ang;									// angle should be reversed (Quadrant 2 and 4)
 	}
	uint8_t val = pgm_read_byte(&quarter_sine[ang]);	// get the value from the table
 	if (quad & 0x02)
 	{
 		val = 255 - val;								// invert value (Quadrant 3 and 4)
 	}
	if (val >= 128)
	{
		return (val - 128) << 1;
	}
	else
	{
		return 0;
	}
}

/* 
 * Turn output V1 and V2 off
 */
void v12_off(void)
{
	TCD5.CCABUF = 0;									// OC5A set to 0% duty cycle (V1_EN)
	TCD5.CCBBUF = 0;									// OC5B set to 0% duty cycle (V2_EN)
	TCD5.CTRLGSET = TC_CMD_UPDATE_gc;					// Force TCD5 timer UPDATE
}

/* 
 * Turn output V1 on
 */
void v1_on(void)
{
	TCD5.CCABUF = OUT_PWM_PERIOD;						// OC5A set to 100% duty cycle (V1_EN)
}

/* 
 * Turn output V1 off
 */
void v1_off(void)
{
	TCD5.CCABUF = 0;									// OC5A set to 0% duty cycle (V1_EN)
}

/* 
 * Turn output V2 on
 */
void v2_on(void)
{
	TCD5.CCBBUF = OUT_PWM_PERIOD;						// OC5B set to 100% duty cycle (V2_EN)
}

/* 
 * Turn output V2 off
 */
void v2_off(void)
{
	TCD5.CCBBUF = 0;									// OC5B set to 100% duty cycle (V2_EN)
}
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
int main(void)
{
	uint8_t  power_state = SM_POWER_RESET;				// Current power state
	uint8_t  prog_state = SM_PROG_RESET;				// Current programming state
	uint8_t  prog_count = 0;							// Program ON time count in number of # minutes
	uint8_t  prog_led = 0;								// Program mode LED on state

	// Number of minutes to stay on when ignition is off
	uint32_t  delay_time_ms = eeprom_read_dword(&eeprom_delay_time_ms);
	
	// Disable the Watchdog timer on start
	wdt_disable();
    // main loop forever
    while (TRUE) 
    {
		// Each loop of main reset the Watchdog timer
		wdt_reset();
		
		// Power State Machine
		//   Manages initialization and power down of processor
		switch (power_state)
		{
		case SM_POWER_DOWN:								// Powered Down State
			// See if IGN has switched ON
			if (ign_cur)
			{
				// IGN is ON
				power_state = SM_POWER_ON_IGN;			// Switch to Power ON due to Ignition State
			}
			else if ((sw1_toggle || sw2_toggle) && (delay_time_ms != 0))
			{
				// IGN is OFF, one of the switches were toggled ON and delay time is set to something other than 0
				//  Time to wake up and do something
				power_state = SM_POWER_ON_SW;			// Switch to Power ON due to Switch State
				cli();									// prevent interrupts from corrupting non-atomic instructions
				delay_ms = 0;
				sei();
			}
			else
			{
				// There is nothing to do so Power Down
				horn_off();								// Turn OFF horn
				hswl_off();								// Turn OFF horn RGD LED indicators
				wdt_disable();							// Disable the watchdog timer before going to sleep
 				TCC4.CTRLA = TC_CLKSEL_OFF_gc;			// TCC4 Clock is OFF
				TCC5.CTRLA = TC_CLKSEL_OFF_gc;			// TCC5 Clock is OFF
				TCD5.CTRLA = TC_CLKSEL_OFF_gc;			// TCD5 Clock is OFF
				REV_port.INTMASK &= ~(1 << REV_bp)		// REV Input Change Interrupt interrupt disabled
								 &  ~(1 << HB_bp);		// HB Input Change Interrupt interrupt disabled
				set_sleep_mode(SLEEP_SMODE_PSAVE_gc);	// Set Power Down Mode when sleep is executed
				sleep_mode();							// Enter Power Down State now
				REV_port.INTMASK |= (1 << REV_bp) 		// REV Input Change Interrupt interrupt enabled
								 |  (1 << HB_bp);		// HB Input Change Interrupt interrupt enabled
 				TCC4.CTRLA = TC_CLKSEL_DIV64_gc;		// Clock is main/64 or 2MHz/64 or 31.25kHz
 				TCC4.CTRLC = (0 << TC4_POLA_bp)			// Non-Invert OC4A output (Not used)
 						   | (1 << TC4_POLB_bp)			// Invert OC4B output (HSWLB_EN)
 						   | (1 << TC4_POLC_bp)			// Invert OC4C output (HSWLG_EN)
 						   | (1 << TC4_POLD_bp)			// Invert OC4D output (HSWLR_EN)
 						   | (0 << TC4_CMPA_bp)			// Force OC4A output OFF (Not used)
 						   | (0 << TC4_CMPB_bp)			// Force OC4B output OFF (HSWLB_EN) 
 						   | (0 << TC4_CMPC_bp)			// Force OC4C output OFF (HSWLG_EN)
 						   | (0 << TC4_CMPD_bp);		// Force OC4D output OFF (HSWLR_EN)
				TCC5.CTRLA = TC_CLKSEL_DIV64_gc;		// Clock is main/64 or 2MHz/64 or 31.25kHz
				TCC5.CTRLC = (1 << TC5_POLA_bp)			// Invert OC5A output (SWL2_EN)
						   | (1 << TC5_POLB_bp)			// Invert OC5B output (SWL1_EN)
						   | (0 << TC5_CMPA_bp)			// Force OC5A output OFF (SWL2_EN) OFF
						   | (0 << TC5_CMPB_bp);		// Force OC5B output OFF (SWL1_EN) OFF
				TCD5.CTRLA = TC_CLKSEL_DIV64_gc;		// Clock is main/64 or 2MHz/64 or 31.25kHz
				TCD5.CTRLC = (1 << TC5_POLA_bp)			// Invert OC5A output (V1_EN)
						   | (1 << TC5_POLB_bp)			// Invert OC5D output (V2_EN)
						   | (0 << TC5_CMPA_bp)			// Force OC5A output OFF (V1_EN)
						   | (0 << TC5_CMPB_bp);		// Force OC5B output OFF (V2_EN)
				wdt_reset();							// reset watchdog before enabling it
				wdt_enable(WATCHDOG_TO);				// Enable the Watchdog timer
				continue;								// We were woken from Power Down state, restart the while(TRUE) loop
			}
			break;
		case SM_POWER_ON_IGN:							// Power ON due to Ignition State
			// See if IGN has switched OFF
			if (!ign_cur)
			{
				// IGN switched OFF so Power Down
				power_state = SM_POWER_DOWN;			// Switch to Power Down State
				sw1_toggle = TOGGLE_OFF;				// SW1 toggle forced off when IGN turns off
				sw2_toggle = TOGGLE_OFF;				// SW2 toggle forced off when IGN turns off
			}
			else
			{
				if (hsw_cur)
				{
					// Horn Switch changed
					horn_on();
					// force difference for High Beam and Reverse
					hb_last = !hb_cur;
					rev_last = !rev_last;
				}
				else
				{
					// horn is not engaged
					horn_off();
					if (hb_cur != hb_last)
					{
						// High beam changed
						if (hb_cur)
						{
							// High beam turned ON
							if (sw1_toggle != TOGGLE_ON_USER)
							{
								// SW1 Toggle is not already ON from user request
								sw1_toggle = TOGGLE_ON;	// SW1 Toggle automatically turned ON
							}
						}
						else
						{
							// High beam turned OFF
							if (sw1_toggle != TOGGLE_ON_USER)
							{
								// SW1 Toggle is not already ON from user request
								sw1_toggle = TOGGLE_OFF;// SW1 Toggle automatically turned OFF
							}
						}
						hb_last = hb_cur;
					}
					if (rev_cur != rev_last)
					{
						// Reverse changed
						if (rev_cur)
						{
							// Reverse turned ON
							if (sw2_toggle != TOGGLE_ON_USER)
							{
								// SW2 Toggle is not already ON from user request
								sw2_toggle = TOGGLE_ON;	// SW2 Toggle automatically turned ON
							}
						}
						else
						{
							// Reverse turned OFF
							if (sw2_toggle != TOGGLE_ON_USER)
							{
								// SW2 Toggle is not already ON from user request
								sw2_toggle = TOGGLE_OFF;// SW2 Toggle automatically turned OFF
							}
						}
						rev_last = rev_cur;
					}
				}
			}
			break;
		case SM_POWER_ON_SW:							// Power ON due to Switch State
			if (ign_cur)
			{
				// IGN switched on so we are no longer Power ON due to Switch
				power_state = SM_POWER_ON_IGN;			// Switch to Power ON due to Ignition turning ON
			}
			else if (!sw1_toggle && !sw2_toggle)
			{
				// No switch is active, time to Power Down
				power_state = SM_POWER_DOWN;			// Switch to Power Down State
			}
			else if (delay_ms >= delay_time_ms)
			{
				// Delay timeout
				sw1_toggle =  TOGGLE_OFF;
				sw2_toggle =  TOGGLE_OFF;				// Turn off SW1 and SW2 toggle before entering power down
				power_state = SM_POWER_DOWN;			// Switch to Power Down State
			} 
			break;
		default:
			// Anything else is considered to SM_POWER_RESET
			cli();										// Disable interrupts
			// clock setup
			OSC.CTRL = (1 << OSC_RC32KEN_bp)			// Enable internal 32.768 kHz oscillator
			         | (1 << OSC_RC2MEN_bp);			// Keep internal 2MHz oscillator enabled
			// Initialize IOs, default all pins to input and have pull-downs enabled
			PORTA.DIRCLR = 0xFF;						// PORTA is all inputs
			PORTCFG.MPCMASK = 0xFF;						// Multi-Pin Configuration select all bits
			PORTA.PIN0CTRL = PORT_OPC_PULLDOWN_gc;		// PORTA is all pull-downs
			PORTC.DIRCLR = 0xFF;						// PORTC is all inputs
			PORTCFG.MPCMASK = 0xFF;						// Multi-Pin Configuration select all bits
			PORTC.PIN0CTRL = PORT_OPC_PULLDOWN_gc;		// PORTC is all pull-downs
			PORTD.DIRCLR = 0xFF;						// PORTD is all inputs
			PORTCFG.MPCMASK = 0xFF;						// Multi-Pin Configuration select all bits
			PORTD.PIN0CTRL = PORT_OPC_PULLDOWN_gc;		// PORTD is all pull-downs
			PORTR.DIRCLR = 0xFF;						// PORTR is all inputs
			PORTCFG.MPCMASK = 0xFF;						// Multi-Pin Configuration select all bits
			PORTR.PIN0CTRL = PORT_OPC_PULLDOWN_gc;		// PORTR is all pull-downs
			// Configure IGN input
			PORTCFG.MPCMASK = (1 << IGN_bp);			// Multi-Pin Configuration select input
			IGN_port.PIN0CTRL = PORT_OPC_TOTEM_gc		// Input is not pulled down
			                  | PORT_ISC_BOTHEDGES_gc;	// Input interrupt on any edge
			IGN_port.INTCTRL = PORT_INTLVL_HI_gc;		// Interrupt will be high level
			IGN_port.INTMASK |= (1 << IGN_bp);			// Input interrupt enabled
			// Configure REV input
			PORTCFG.MPCMASK = (1 << REV_bp);			// Multi-Pin Configuration select input
			REV_port.PIN0CTRL = PORT_OPC_TOTEM_gc		// Input is not pulled down
			                  | PORT_ISC_BOTHEDGES_gc;	// Input interrupt on any edge
			REV_port.INTCTRL = PORT_INTLVL_HI_gc;		// Interrupt will be high level
			REV_port.INTMASK |= (1 << REV_bp);			// Input interrupt enabled
			// Configure HB input
			PORTCFG.MPCMASK = (1 << HB_bp);				// Multi-Pin Configuration select input
			HB_port.PIN0CTRL = PORT_OPC_TOTEM_gc		// Input is not pulled down
			                 | PORT_ISC_BOTHEDGES_gc;	// Input interrupt on any edge
			HB_port.INTCTRL = PORT_INTLVL_HI_gc;		// Interrupt will be high level
			HB_port.INTMASK |= (1 << HB_bp);			// Input interrupt enabled
			// Configure HSW input
			PORTCFG.MPCMASK = (1 << HSW_bp);			// Multi-Pin Configuration select input
			HSW_port.PIN0CTRL = PORT_OPC_TOTEM_gc		// Input is not pulled down
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

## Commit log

2020-11-22 Update board images.
2020-11-22 Update board images
